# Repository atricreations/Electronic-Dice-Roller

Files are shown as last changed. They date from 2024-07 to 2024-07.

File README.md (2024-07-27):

# Electronic-Dice-Roller.

Repository containing all the necessary files for the Electronic Dice Roller by Atricreations. 

There are 3 primary components to this repository:
- Code: The main micro python files for the RP2040 micro controller.
- 3D-Models: STL files that make up the case.
- PCB: Ki-cad PCB design files.

### What do this do?
This is the current iteration of a long running project seeking to implement electronic dice. This design features:
- RP2040 Microcontroller
- Fully RGB 5x7 matrix display
- Lithium battery and charger

The code is fully open source and the design is to encourage tinkering. The current design isn't perfect but is highly functional. As updates are made they will be posted here. 

 If you like what is here consider buying one or some of the components off of our Etsy. 
### How do I modify the software on my dice? 
 All complete dice come sold with the current version of software installed. If you would like to update the software you need to copy the files from the Code directory onto your device. Primarily this is done through [Thonny](https://thonny.org/). 
 
When a source file is opened on Thonny and the correct interface is selected, you can upload the new source file onto the micorcontroller. All files need to be updated for them to work properly. 

### I need help!!!!
Don't hesitate to email us at Atricreations@gmail.com if you need help with your unit. We may take a while to respond but we can offer help if needed. 

### History:
-V 0.1: 7/26/2024 -  Initial Beta Release - Highly functional, lacks low power features, a few small bugs. 

## Todo: 
### PCB:
- Add Accelerometer.
- Add Speaker.
### 3D Models:
- Improved Tolerances.
### Code:
- Improved low power performance (possibly port to circuitpython).
- Various bug fixes.
- Some type of config file to determine color encoding.
- Some type of encoding for animations and other effects.
- PC application to upload configurations.
- Endless feature creep. 

## License
Electronic Dice Roller © 2024 by Atricareations is licensed under CC BY-NC 4.0. To view a copy of this license, visit https://creativecommons.org/licenses/by-nc/4.0/

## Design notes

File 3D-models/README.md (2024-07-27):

# 3D Models
This folder contains the mesh files for 3d printing. The top screen and buttons are multi part assemblies and really are intended to be printed multi-color to get the proper effect. 

A precolored bambulabs project is also included. 

Files were printed with a .2mm nozzle.

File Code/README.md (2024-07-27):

# Source code files
There are a handful of files that make up the source code of this device.

-char_set.py: Courtesy of chatgpt, this included the charaacter set used on the display. 
-config.py: Contains the configuration setting for the device. 
-main.py: Contains the main logic and functions. The entry point for the microcontroller. 
-neopixel.py: Contains the neopixel library.

For the most part, the only files that need to be modified are main.py and config.py, the other files are fairly static.

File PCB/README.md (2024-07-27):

# PCB Design files
This folder contains the Ki-Cad design files for the pCB including the PCB and layout. 

There really isnt much to say here, if you are fammiliar with PCB design you'll know what to do. If not, feel free to ask questions but the design isnt completely trivial.

The design uses all LCSC parts and can be ordered fully assembled through JLCPCB.

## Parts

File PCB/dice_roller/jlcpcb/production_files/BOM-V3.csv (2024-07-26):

Comment | Designator | Footprint | LCSC
1k | R17,R20,R6,R8 | R_0402_1005Metric | C11702
22uf | C10,C2,C5,C9 | C_0402_1005Metric | C15525
8p | C21,C22 | C_0402_1005Metric | C161335
1UH | L1 | IND-SMD_L4.4-W4.2 | C167203
0 | R10,R12,R14,R15,R16,R9 | R_0402_1005Metric | C17168
IP5306 | U1 | ESOP-8_L4.9-W3.9-P1.27-LS6.0-BL-EP | C181692
LED | D1 | LED_0603_1608Metric | C2286
20R | R21 | R_0402_1005Metric | C25092
10k | R4 | R_0402_1005Metric | C25744
5.1K | R1,R3 | R_0402_1005Metric | C25905
1M | R18,R19 | R_0402_1005Metric | C26083
TYPE-C 16PIN 2MD(073) | USB1 | USB-C-SMD_TYPE-C-6PIN-2MD-073 | C2765186
SK6805-EC20 | LED1,LED10,LED11,LED12,LED13,LED14,LED15,LED16,LED17,LED18,LED19,LED2,LED20,LED21,LED22,LED23,LED24,LED25,LED26,LED27,LED28,LED29,LED3,LED30,LED31,LED32,LED33,LED34,LED35,LED36,LED37,LED38,LED39,LED4,LED40,LED41,LED42,LED43,LED44,LED45,LED46,LED47,LED48,LED49,LED5,LED50,LED51,LED52,LED53,LED54,LED55,LED56,LED57,LED58,LED59,LED6,LED60,LED61,LED62,LED63,LED64,LED65,LED66,LED67,LED68,LED69,LED7,LED70,LED71,LED72,LED73,LED74,LED75,LED76,LED77,LED8,LED9 | LED-SMD_4P-L2.0-W2.0-BR | C2890036
100n | C1,C11,C12,C13,C14,C15,C16,C17,C18,C19,C23,C24,C25,C26,C27,C28,C29,C3,C30,C31,C32,C33,C34,C35,C36,C37,C38,C39,C4,C40,C41,C42,C43,C44,C45,C46,C47,C48,C49,C50,C51,C52,C53,C54,C55,C56,C57,C58,C59,C6,C60,C61,C62,C63,C64,C65,C66,C67,C7,C8 | C_0402_1005Metric | C307331
27.4 | R11,R13 | R_0402_1005Metric | C31439
BOOT | S2,S3,S4,S5,S6 | SW_TS-1187A-B-A-B | C318884
TS24CA | SW1 | SW-SMD_TS24CA | C393942
LM4040DBZ-2.0 | U2 | SOT-23 | C460725
0.5R | R2 | R_0402_1005Metric | C5204041
1u | C20 | C_0402_1005Metric | C52923
MCP1703Ax-330xxTT | U3 | SOT-23 | C5446
WTL2M45316LZ | X1 | CRYSTAL-SMD_4P-L2.5-W2.0-BL | C963522
W25Q128JVS | U4 | SOIC-8_5.23x5.23mm_P1.27mm | C97521
RP2040 | U5 | QFN-56-1EP_7x7mm_P0.4mm_EP3.2x3.2mm

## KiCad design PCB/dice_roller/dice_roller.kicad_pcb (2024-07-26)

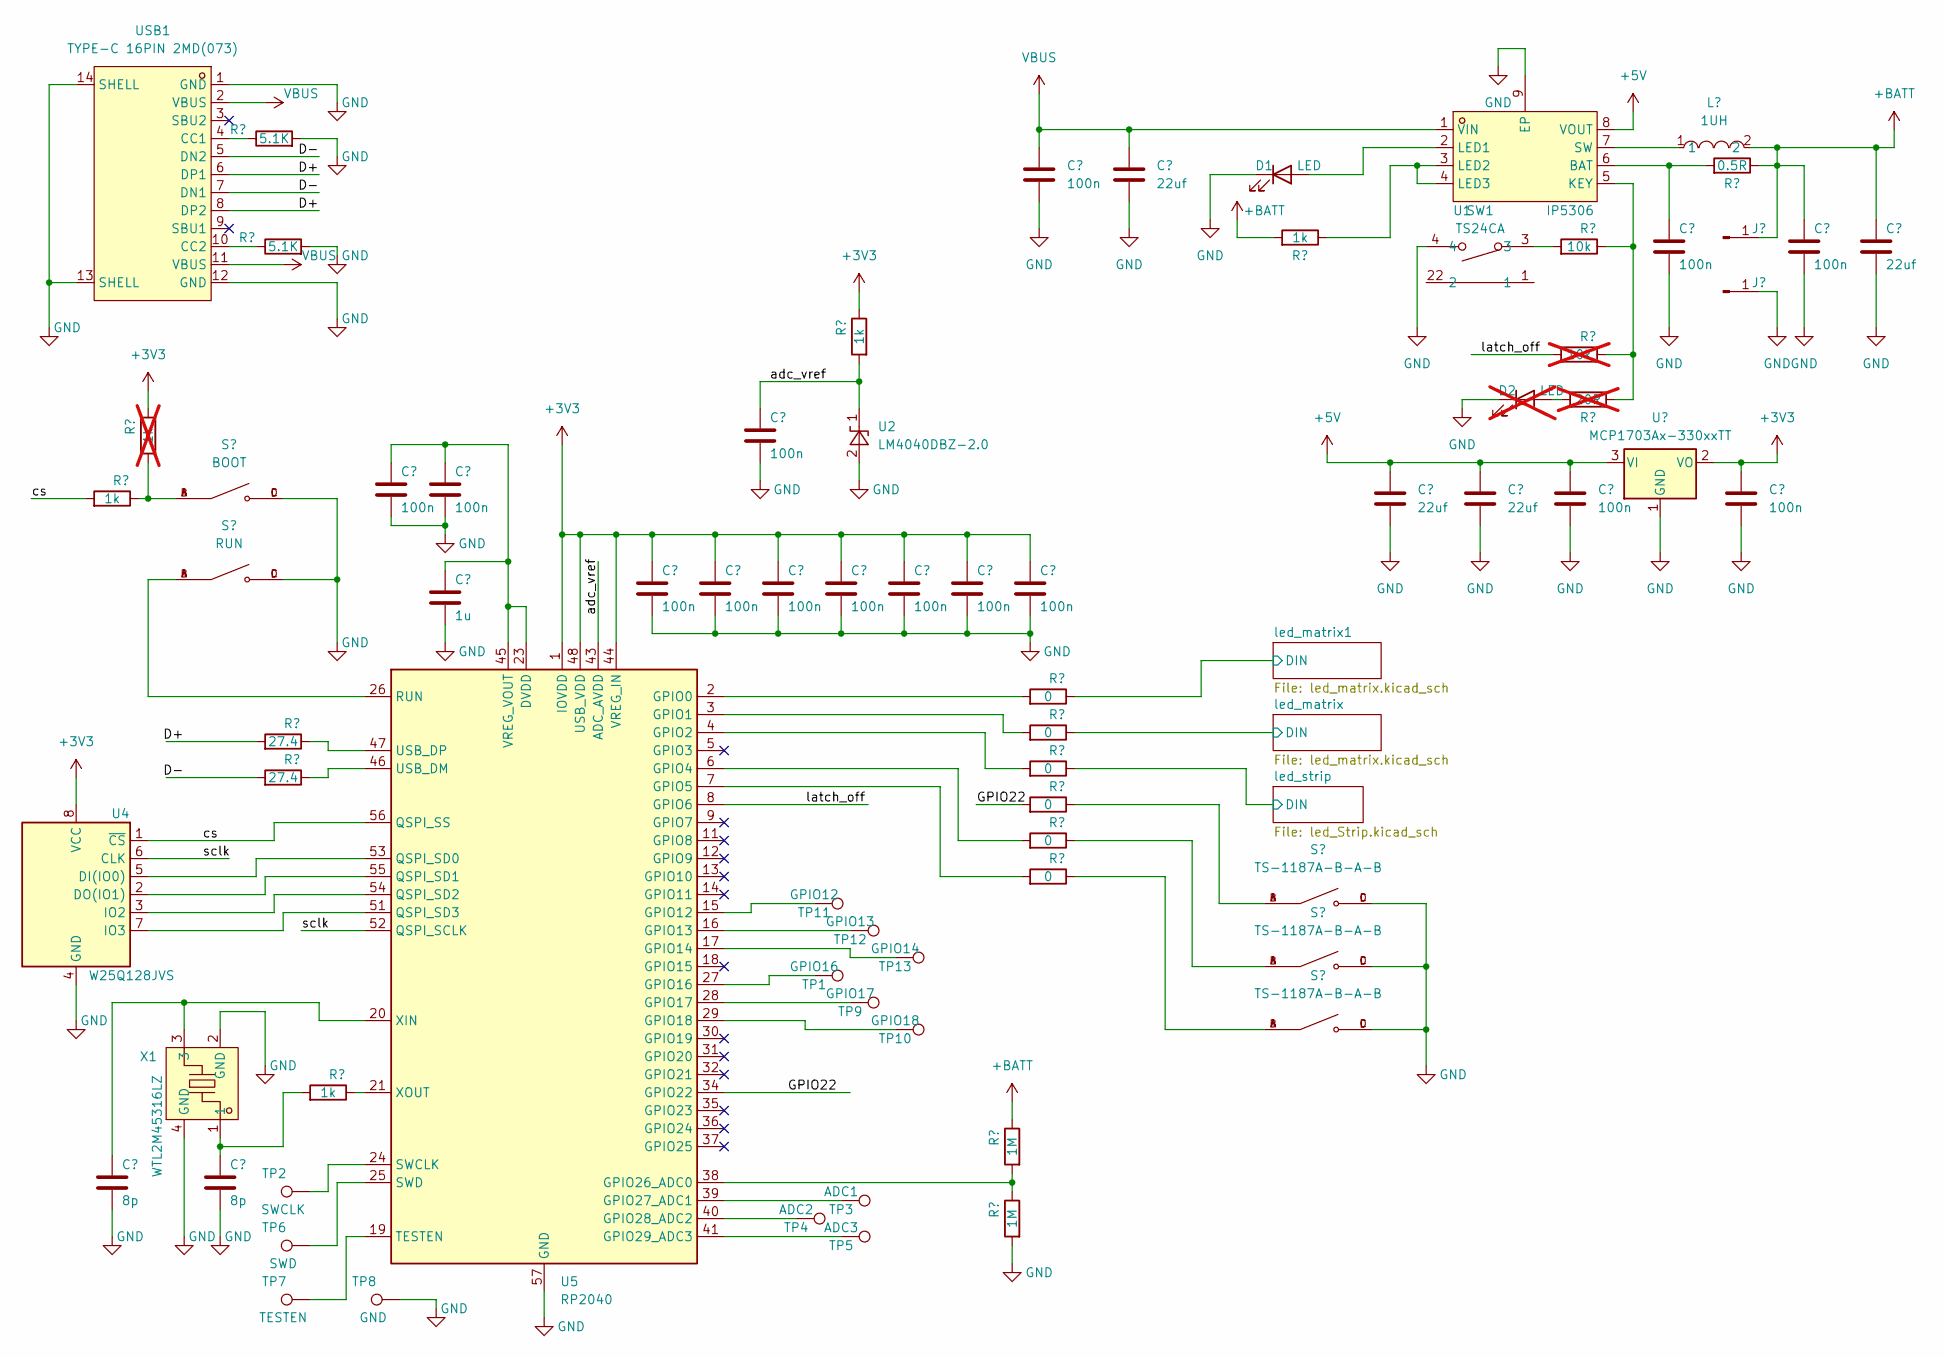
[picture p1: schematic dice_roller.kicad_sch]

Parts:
C1, C3, C4, C6, C7, C8, C11, C12, C13, C14, C15, C16, C17, C18, C19: 100n; C_0402_1005Metric
C2, C5, C9, C10: 22uf; C_0402_1005Metric
C20: 1u; C_0402_1005Metric
C21, C22: 8p; C_0402_1005Metric
D1: LED; LED_0603_1608Metric
D2: LED; LED_0603_1608Metric; not fitted
J1, J2: Conn_01x01_Pin; TestPoint_Pad_2.0x2.0mm
L1: 1UH; IND-SMD_L4.4-W4.2; LCSC Part C167203
R1, R3: 5.1K; R_0402_1005Metric
R2: 0.5R; R_0402_1005Metric
R4: 10k; R_0402_1005Metric
R5: 10k; R_0402_1005Metric; not fitted
R6, R8, R17, R20: 1k; R_0402_1005Metric
R7: 1k; R_0402_1005Metric; not fitted
R9, R10, R12, R14, R15, R16: 0; R_0402_1005Metric
R11, R13: 27.4; R_0402_1005Metric
R18, R19: 1M; R_0402_1005Metric
R21: 20R; R_0402_1005Metric; not fitted
S2: BOOT; SW_TS-1187A-B-A-B; PARTREV A0
S3: RUN; SW_TS-1187A-B-A-B; PARTREV A0
S4, S5, S6: TS-1187A-B-A-B; SW_TS-1187A-B-A-B; PARTREV A0
SW1: TS24CA; SW-SMD_TS24CA; LCSC Part C393942
TP1: GPIO16; TestPoint_Pad_D1.0mm
TP2: SWCLK; TestPoint_Pad_D1.0mm
TP3: ADC1; TestPoint_Pad_D1.0mm
TP4: ADC2; TestPoint_Pad_D1.0mm
TP5: ADC3; TestPoint_Pad_D1.0mm
TP6: SWD; TestPoint_Pad_D1.0mm
TP7: TESTEN; TestPoint_Pad_D1.0mm
TP8: GND; TestPoint_Pad_1.0x1.0mm
TP9: GPIO17; TestPoint_Pad_D1.0mm
TP10: GPIO18; TestPoint_Pad_D1.0mm
TP11: GPIO12; TestPoint_Pad_D1.0mm
TP12: GPIO13; TestPoint_Pad_D1.0mm
TP13: GPIO14; TestPoint_Pad_D1.0mm
U1: IP5306; ESOP-8_L4.9-W3.9-P1.27-LS6.0-BL-EP; LCSC Part C181692
U2: LM4040DBZ-2.0; SOT-23
U3: MCP1703Ax-330xxTT; SOT-23
U4: W25Q128JVS; SOIC-8_5.23x5.23mm_P1.27mm
U5: RP2040; QFN-56-1EP_7x7mm_P0.4mm_EP3.2x3.2mm
USB1: TYPE-C 16PIN 2MD(073); USB-C-SMD_TYPE-C-6PIN-2MD-073; LCSC Part C2765186
X1: WTL2M45316LZ; CRYSTAL-SMD_4P-L2.5-W2.0-BL; LCSC Part C963522

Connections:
+3V3: C12.1, C13.1, C14.1, C15.1, C16.1, C17.1, C18.1, C19.1, R6.1, R7.1, U3.2 (VO), U4.8 (VCC), U5.1 (IOVDD), U5.10 (IOVDD), U5.22 (IOVDD), U5.33 (IOVDD), U5.42 (IOVDD), U5.44 (VREG_IN), U5.48 (USB_VDD), U5.49 (IOVDD)
+5V: C9.1, C10.1, C11.1, U1.8 (VOUT), U3.3 (VI); also elsewhere on the board
+BATT: C4.1, C5.1, J1.1, L1.2, R2.1, R18.1, R20.2
/D+: R11.2, USB1.6 (DP1), USB1.8 (DP2)
/D-: R13.2, USB1.5 (DN2), USB1.7 (DN1)
/GPIO22: R14.2, U5.34 (GPIO22)
/adc_vref: C6.1, R6.2, U2.1 (K), U5.43 (ADC_AVDD)
/cs: R8.2, U4.1 (~CS), U5.56 (QSPI_SS)
/latch_off: R5.2, U5.8 (GPIO6)
/led_matrix1/DIN: R9.1; also elsewhere on the board
/led_matrix/DIN: R10.1; also elsewhere on the board
/led_strip/DIN: R12.1; also elsewhere on the board
/sclk: U4.6 (CLK), U5.52 (QSPI_SCLK)
GND: C1.2, C2.2, C3.2, C4.2, C5.2, C6.2, C7.2, C8.2, C9.2, C10.2, C11.2, C12.2, C13.2, C14.2, C15.2, C16.2, C17.2, C18.2, C19.2, C20.2, C21.2, C22.2, D1.1 (K), D2.1 (K), J2.1, R1.2, R3.2, R19.2, S2.C, S2.D, S3.C, S3.D, S4.C, S4.D, S5.C, S5.D, S6.C, S6.D, SW1.4, TP8.1, U1.9 (EP), U2.2 (A), U3.1 (GND), U4.4 (GND), U5.57 (GND), USB1.1 (GND), USB1.12 (GND), USB1.13 (SHELL), USB1.14 (SHELL), X1.2 (GND), X1.4 (GND); also elsewhere on the board
unnamed: C22.1, R17.2, X1.1
unnamed: D1.2 (A), U1.2 (LED1)
unnamed: D2.2 (A), R21.2
unnamed: R4.2, SW1.3
unnamed: R7.2, R8.1, S2.A, S2.B
unnamed: R14.1, S4.A, S4.B
unnamed: R15.1, S5.A, S5.B
unnamed: R16.1, S6.A, S6.B
unnamed: C3.1, R2.2, U1.6 (BAT)
unnamed: R4.1, R5.1, R21.1, U1.5 (KEY)
unnamed: R20.1, U1.3 (LED2), U1.4 (LED3)
unnamed: L1.1, U1.7 (SW)
unnamed: U4.5 (DI(IO0)), U5.53 (QSPI_SD0)
unnamed: U4.2 (DO(IO1)), U5.55 (QSPI_SD1)
unnamed: U4.3 (IO2), U5.54 (QSPI_SD2)
unnamed: U4.7 (IO3), U5.51 (QSPI_SD3)
unnamed: R9.2, U5.2 (GPIO0)
unnamed: R10.2, U5.3 (GPIO1)
unnamed: R12.2, U5.4 (GPIO2)
unnamed: R15.2, U5.6 (GPIO4)
unnamed: R16.2, U5.7 (GPIO5)
unnamed: TP11.1, U5.15 (GPIO12)
unnamed: TP12.1, U5.16 (GPIO13)
unnamed: TP13.1, U5.17 (GPIO14)
unnamed: TP1.1, U5.27 (GPIO16)
unnamed: TP9.1, U5.28 (GPIO17)
unnamed: TP10.1, U5.29 (GPIO18)
unnamed: R18.2, R19.1, U5.38 (GPIO26_ADC0)
unnamed: TP3.1, U5.39 (GPIO27_ADC1)
unnamed: TP4.1, U5.40 (GPIO28_ADC2)
unnamed: TP5.1, U5.41 (GPIO29_ADC3)
unnamed: S3.A, S3.B, U5.26 (RUN)
unnamed: TP2.1, U5.24 (SWCLK)
unnamed: TP6.1, U5.25 (SWD)
unnamed: TP7.1, U5.19 (TESTEN)
unnamed: R13.1, U5.46 (USB_DM)
unnamed: R11.1, U5.47 (USB_DP)
unnamed: C7.1, C8.1, C20.1, U5.23 (DVDD), U5.45 (VREG_VOUT), U5.50 (DVDD)
unnamed: C21.1, U5.20 (XIN), X1.3
unnamed: R17.1, U5.21 (XOUT)
unnamed: R1.1, USB1.4 (CC1)
unnamed: R3.1, USB1.10 (CC2)
VBUS: C1.1, C2.1, U1.1 (VIN), USB1.2 (VBUS), USB1.11 (VBUS)

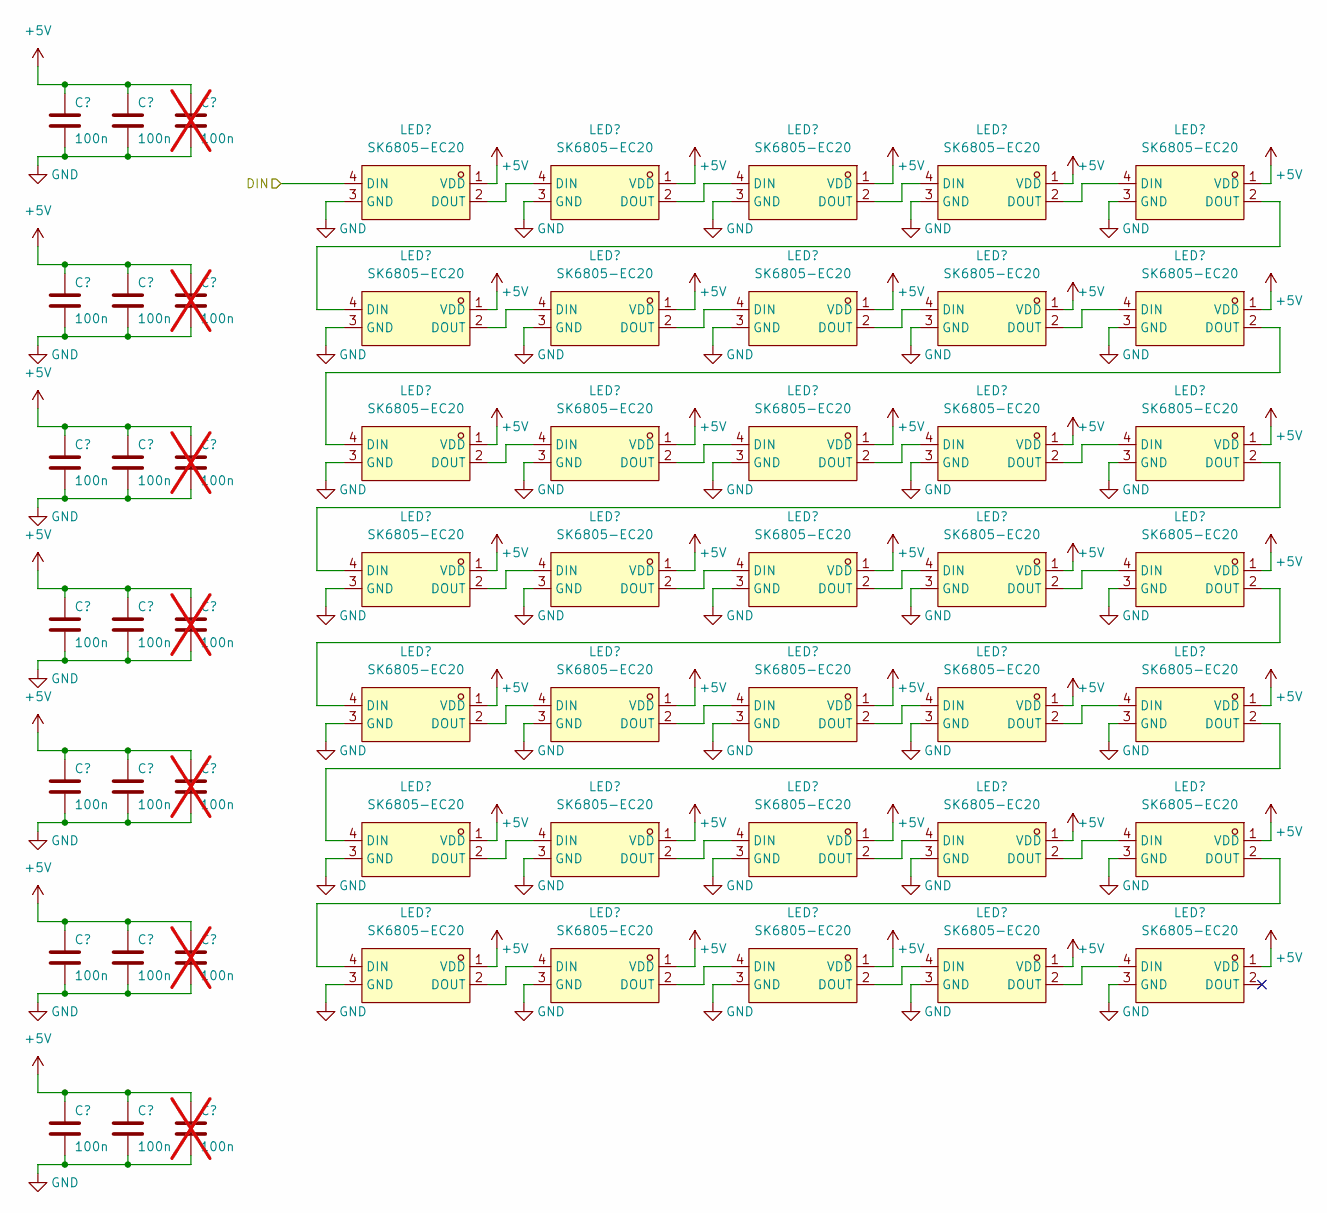
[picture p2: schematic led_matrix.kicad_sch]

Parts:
C23, C24, C26, C27, C29, C30, C32, C33, C35, C36, C38, C39, C41, C42: 100n; C_0402_1005Metric
C25, C28, C31, C34, C37, C40, C43: 100n; C_0402_1005Metric; not fitted
LED1, LED2, LED3, LED4, LED5, LED6, LED7, LED8, LED9, LED10, LED11, LED12, LED13, LED14, LED15, LED16, LED17, LED18, LED19, LED20, LED21, LED22, LED23, LED24, LED25, LED26, LED27, LED28, LED29, LED30, LED31, LED32, LED33, LED34, LED35: SK6805-EC20; LED-SMD_4P-L2.0-W2.0-BR; LCSC Part C2890036

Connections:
+5V: C23.1, C24.1, C25.1, C26.1, C27.1, C28.1, C29.1, C30.1, C31.1, C32.1, C33.1, C34.1, C35.1, C36.1, C37.1, C38.1, C39.1, C40.1, C41.1, C42.1, C43.1, LED1.1 (VDD), LED2.1 (VDD), LED3.1 (VDD), LED4.1 (VDD), LED5.1 (VDD), LED6.1 (VDD), LED7.1 (VDD), LED8.1 (VDD), LED9.1 (VDD), LED10.1 (VDD), LED11.1 (VDD), LED12.1 (VDD), LED13.1 (VDD), LED14.1 (VDD), LED15.1 (VDD), LED16.1 (VDD), LED17.1 (VDD), LED18.1 (VDD), LED19.1 (VDD), LED20.1 (VDD), LED21.1 (VDD), LED22.1 (VDD), LED23.1 (VDD), LED24.1 (VDD), LED25.1 (VDD), LED26.1 (VDD), LED27.1 (VDD), LED28.1 (VDD), LED29.1 (VDD), LED30.1 (VDD), LED31.1 (VDD), LED32.1 (VDD), LED33.1 (VDD), LED34.1 (VDD), LED35.1 (VDD); also elsewhere on the board
/led_matrix/DIN: LED1.4 (DIN); also elsewhere on the board
GND: C23.2, C24.2, C25.2, C26.2, C27.2, C28.2, C29.2, C30.2, C31.2, C32.2, C33.2, C34.2, C35.2, C36.2, C37.2, C38.2, C39.2, C40.2, C41.2, C42.2, C43.2, LED1.3 (GND), LED2.3 (GND), LED3.3 (GND), LED4.3 (GND), LED5.3 (GND), LED6.3 (GND), LED7.3 (GND), LED8.3 (GND), LED9.3 (GND), LED10.3 (GND), LED11.3 (GND), LED12.3 (GND), LED13.3 (GND), LED14.3 (GND), LED15.3 (GND), LED16.3 (GND), LED17.3 (GND), LED18.3 (GND), LED19.3 (GND), LED20.3 (GND), LED21.3 (GND), LED22.3 (GND), LED23.3 (GND), LED24.3 (GND), LED25.3 (GND), LED26.3 (GND), LED27.3 (GND), LED28.3 (GND), LED29.3 (GND), LED30.3 (GND), LED31.3 (GND), LED32.3 (GND), LED33.3 (GND), LED34.3 (GND), LED35.3 (GND); also elsewhere on the board
unnamed: LED1.2 (DOUT), LED2.4 (DIN)
unnamed: LED2.2 (DOUT), LED3.4 (DIN)
unnamed: LED3.2 (DOUT), LED4.4 (DIN)
unnamed: LED4.2 (DOUT), LED5.4 (DIN)
unnamed: LED5.2 (DOUT), LED6.4 (DIN)
unnamed: LED6.2 (DOUT), LED7.4 (DIN)
unnamed: LED7.2 (DOUT), LED8.4 (DIN)
unnamed: LED8.2 (DOUT), LED9.4 (DIN)
unnamed: LED9.2 (DOUT), LED10.4 (DIN)
unnamed: LED10.2 (DOUT), LED11.4 (DIN)
unnamed: LED11.2 (DOUT), LED12.4 (DIN)
unnamed: LED12.2 (DOUT), LED13.4 (DIN)
unnamed: LED13.2 (DOUT), LED14.4 (DIN)
unnamed: LED14.2 (DOUT), LED15.4 (DIN)
unnamed: LED15.2 (DOUT), LED16.4 (DIN)
unnamed: LED16.2 (DOUT), LED17.4 (DIN)
unnamed: LED17.2 (DOUT), LED18.4 (DIN)
unnamed: LED18.2 (DOUT), LED19.4 (DIN)
unnamed: LED19.2 (DOUT), LED20.4 (DIN)
unnamed: LED20.2 (DOUT), LED21.4 (DIN)
unnamed: LED21.2 (DOUT), LED22.4 (DIN)
unnamed: LED22.2 (DOUT), LED23.4 (DIN)
unnamed: LED23.2 (DOUT), LED24.4 (DIN)
unnamed: LED24.2 (DOUT), LED25.4 (DIN)
unnamed: LED25.2 (DOUT), LED26.4 (DIN)
unnamed: LED26.2 (DOUT), LED27.4 (DIN)
unnamed: LED27.2 (DOUT), LED28.4 (DIN)
unnamed: LED28.2 (DOUT), LED29.4 (DIN)
unnamed: LED29.2 (DOUT), LED30.4 (DIN)
unnamed: LED30.2 (DOUT), LED31.4 (DIN)
unnamed: LED31.2 (DOUT), LED32.4 (DIN)
unnamed: LED32.2 (DOUT), LED33.4 (DIN)
unnamed: LED33.2 (DOUT), LED34.4 (DIN)
unnamed: LED34.2 (DOUT), LED35.4 (DIN)

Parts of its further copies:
C44, C45, C47, C48, C50, C51, C53, C54, C56, C57, C59, C60, C62, C63: 100n; C_0402_1005Metric
C46, C49, C52, C55, C58, C61, C64: 100n; C_0402_1005Metric; not fitted
LED36, LED37, LED38, LED39, LED40, LED41, LED42, LED43, LED44, LED45, LED46, LED47, LED48, LED49, LED50, LED51, LED52, LED53, LED54, LED55, LED56, LED57, LED58, LED59, LED60, LED61, LED62, LED63, LED64, LED65, LED66, LED67, LED68, LED69, LED70: SK6805-EC20; LED-SMD_4P-L2.0-W2.0-BR; LCSC Part C2890036

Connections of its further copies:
+5V: C44.1, C45.1, C46.1, C47.1, C48.1, C49.1, C50.1, C51.1, C52.1, C53.1, C54.1, C55.1, C56.1, C57.1, C58.1, C59.1, C60.1, C61.1, C62.1, C63.1, C64.1, LED36.1 (VDD), LED37.1 (VDD), LED38.1 (VDD), LED39.1 (VDD), LED40.1 (VDD), LED41.1 (VDD), LED42.1 (VDD), LED43.1 (VDD), LED44.1 (VDD), LED45.1 (VDD), LED46.1 (VDD), LED47.1 (VDD), LED48.1 (VDD), LED49.1 (VDD), LED50.1 (VDD), LED51.1 (VDD), LED52.1 (VDD), LED53.1 (VDD), LED54.1 (VDD), LED55.1 (VDD), LED56.1 (VDD), LED57.1 (VDD), LED58.1 (VDD), LED59.1 (VDD), LED60.1 (VDD), LED61.1 (VDD), LED62.1 (VDD), LED63.1 (VDD), LED64.1 (VDD), LED65.1 (VDD), LED66.1 (VDD), LED67.1 (VDD), LED68.1 (VDD), LED69.1 (VDD), LED70.1 (VDD); also elsewhere on the board
/led_matrix1/DIN: LED36.4 (DIN); also elsewhere on the board
GND: C44.2, C45.2, C46.2, C47.2, C48.2, C49.2, C50.2, C51.2, C52.2, C53.2, C54.2, C55.2, C56.2, C57.2, C58.2, C59.2, C60.2, C61.2, C62.2, C63.2, C64.2, LED36.3 (GND), LED37.3 (GND), LED38.3 (GND), LED39.3 (GND), LED40.3 (GND), LED41.3 (GND), LED42.3 (GND), LED43.3 (GND), LED44.3 (GND), LED45.3 (GND), LED46.3 (GND), LED47.3 (GND), LED48.3 (GND), LED49.3 (GND), LED50.3 (GND), LED51.3 (GND), LED52.3 (GND), LED53.3 (GND), LED54.3 (GND), LED55.3 (GND), LED56.3 (GND), LED57.3 (GND), LED58.3 (GND), LED59.3 (GND), LED60.3 (GND), LED61.3 (GND), LED62.3 (GND), LED63.3 (GND), LED64.3 (GND), LED65.3 (GND), LED66.3 (GND), LED67.3 (GND), LED68.3 (GND), LED69.3 (GND), LED70.3 (GND); also elsewhere on the board
unnamed: LED36.2 (DOUT), LED37.4 (DIN)
unnamed: LED37.2 (DOUT), LED38.4 (DIN)
unnamed: LED38.2 (DOUT), LED39.4 (DIN)
unnamed: LED39.2 (DOUT), LED40.4 (DIN)
unnamed: LED40.2 (DOUT), LED41.4 (DIN)
unnamed: LED41.2 (DOUT), LED42.4 (DIN)
unnamed: LED42.2 (DOUT), LED43.4 (DIN)
unnamed: LED43.2 (DOUT), LED44.4 (DIN)
unnamed: LED44.2 (DOUT), LED45.4 (DIN)
unnamed: LED45.2 (DOUT), LED46.4 (DIN)
unnamed: LED46.2 (DOUT), LED47.4 (DIN)
unnamed: LED47.2 (DOUT), LED48.4 (DIN)
unnamed: LED48.2 (DOUT), LED49.4 (DIN)
unnamed: LED49.2 (DOUT), LED50.4 (DIN)
unnamed: LED50.2 (DOUT), LED51.4 (DIN)
unnamed: LED51.2 (DOUT), LED52.4 (DIN)
unnamed: LED52.2 (DOUT), LED53.4 (DIN)
unnamed: LED53.2 (DOUT), LED54.4 (DIN)
unnamed: LED54.2 (DOUT), LED55.4 (DIN)
unnamed: LED55.2 (DOUT), LED56.4 (DIN)
unnamed: LED56.2 (DOUT), LED57.4 (DIN)
unnamed: LED57.2 (DOUT), LED58.4 (DIN)
unnamed: LED58.2 (DOUT), LED59.4 (DIN)
unnamed: LED59.2 (DOUT), LED60.4 (DIN)
unnamed: LED60.2 (DOUT), LED61.4 (DIN)
unnamed: LED61.2 (DOUT), LED62.4 (DIN)
unnamed: LED62.2 (DOUT), LED63.4 (DIN)
unnamed: LED63.2 (DOUT), LED64.4 (DIN)
unnamed: LED64.2 (DOUT), LED65.4 (DIN)
unnamed: LED65.2 (DOUT), LED66.4 (DIN)
unnamed: LED66.2 (DOUT), LED67.4 (DIN)
unnamed: LED67.2 (DOUT), LED68.4 (DIN)
unnamed: LED68.2 (DOUT), LED69.4 (DIN)
unnamed: LED69.2 (DOUT), LED70.4 (DIN)

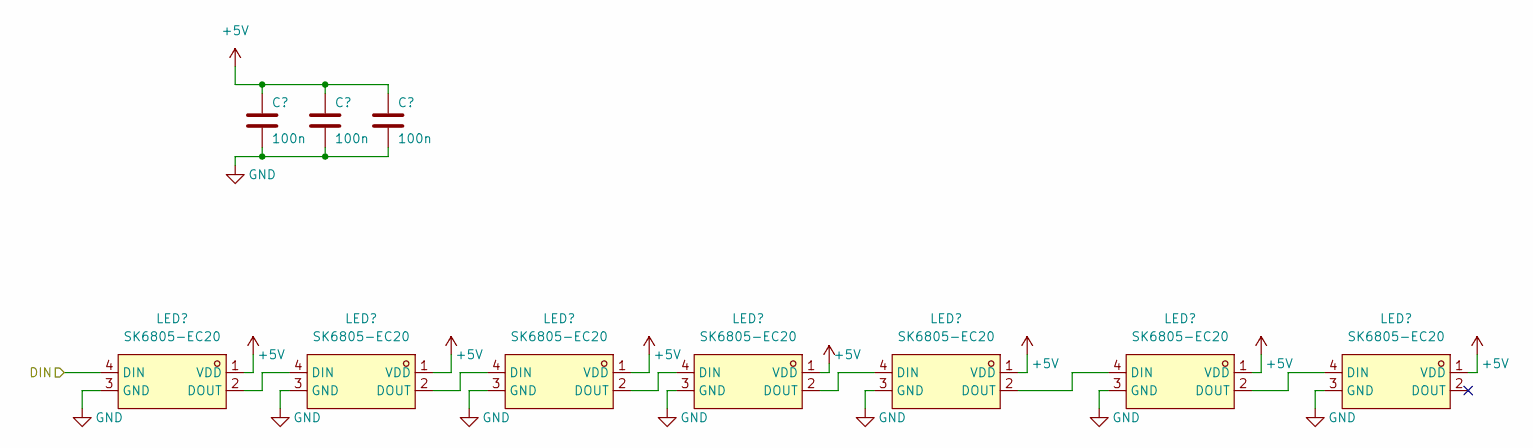
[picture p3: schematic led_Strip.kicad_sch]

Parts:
C65, C66, C67: 100n; C_0402_1005Metric
LED71, LED72, LED73, LED74, LED75, LED76, LED77: SK6805-EC20; LED-SMD_4P-L2.0-W2.0-BR; LCSC Part C2890036

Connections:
+5V: C65.1, C66.1, C67.1, LED71.1 (VDD), LED72.1 (VDD), LED73.1 (VDD), LED74.1 (VDD), LED75.1 (VDD), LED76.1 (VDD), LED77.1 (VDD); also elsewhere on the board
/led_strip/DIN: LED71.4 (DIN); also elsewhere on the board
GND: C65.2, C66.2, C67.2, LED71.3 (GND), LED72.3 (GND), LED73.3 (GND), LED74.3 (GND), LED75.3 (GND), LED76.3 (GND), LED77.3 (GND); also elsewhere on the board
unnamed: LED71.2 (DOUT), LED72.4 (DIN)
unnamed: LED72.2 (DOUT), LED73.4 (DIN)
unnamed: LED73.2 (DOUT), LED74.4 (DIN)
unnamed: LED74.2 (DOUT), LED75.4 (DIN)
unnamed: LED75.2 (DOUT), LED76.4 (DIN)
unnamed: LED76.2 (DOUT), LED77.4 (DIN)

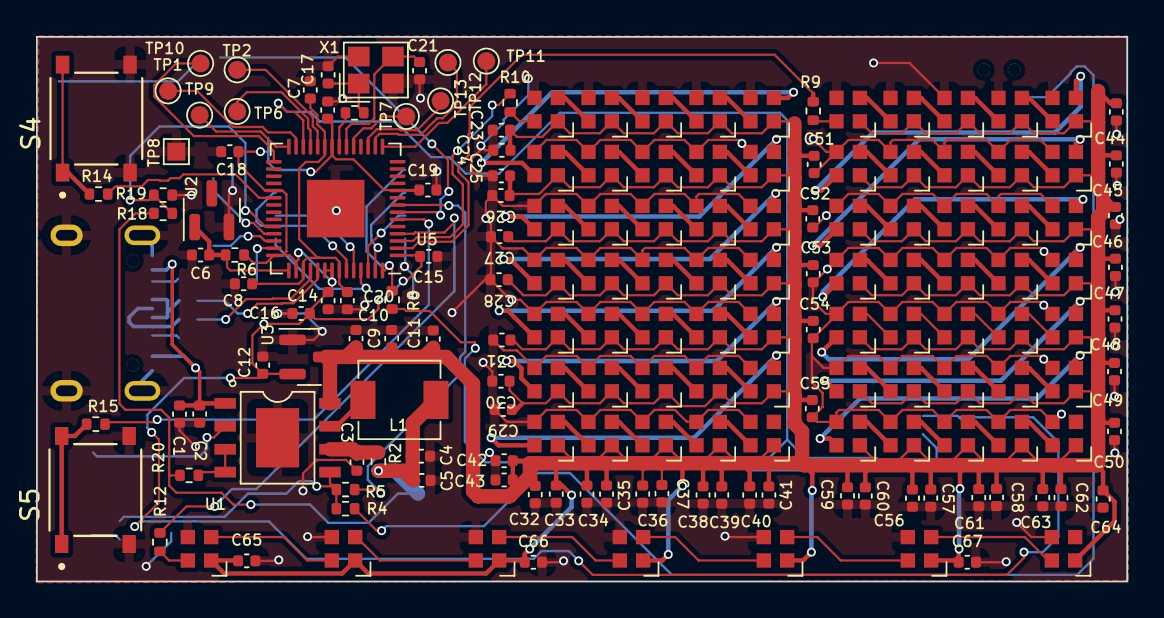
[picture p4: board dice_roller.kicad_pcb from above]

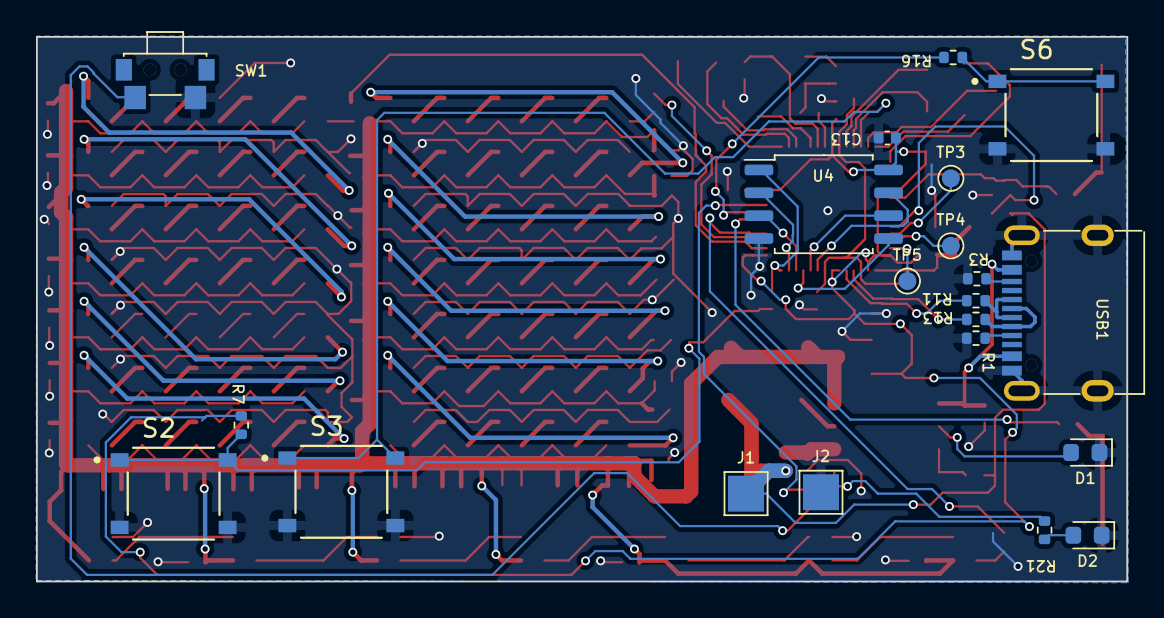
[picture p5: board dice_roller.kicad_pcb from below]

Board: 2 copper layers, 60.6 x 30.3 mm, 196 parts (21 on the bottom side), 131 nets.

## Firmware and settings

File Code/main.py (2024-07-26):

from neopixel import Neopixel
from char_set import char_set
import time
from machine import Pin,ADC,Timer
import random
from config import ones_color, tens_color,sel_color

random.seed()

battery_voltage = ADC(Pin(26))

roll_btn = Pin(4, Pin.IN, machine.Pin.PULL_UP)

switch_btn = Pin(22, Pin.IN, machine.Pin.PULL_UP)

vref = 2.5

n_pixels = 35

pixels = Neopixel(35, 0, 0, "GRB")
pixels_2 = Neopixel(35, 1, 1, "GRB")
pixels_3 = Neopixel(7, 2, 2, "GRB")

# start the timer
start = time.ticks_ms()
debounce_timer = time.ticks_ms()
display_timer = time.ticks_ms()
event_triggered = False

#Display interrupt 60hz/16ms:
def interruption_handler(timer):
    pixels.show()
    pixels_2.show()
    pixels_3.show()
    
show_display = Timer(mode=Timer.PERIODIC, period=16, callback=interruption_handler)
    

#display_vars:
ones = "0"
tens = "0"
value = 0
sel = 0
sleeping = False
display_update = True

button_pressed = None
d_list = [4,6,8,10,12,20,100]

#state_vars:
mode = "roller"
def animation_speckle(n_frames,max_brightness):
    
    for x in range(n_frames):
        for i in range(n_pixels):
            brightness = max_brightness * random.random() 
            pixels.set_pixel(i,[random.random() * brightness,random.random() * brightness,random.random() * brightness])
            pixels_2.set_pixel(i,[random.random() * brightness,random.random() * brightness,random.random() * brightness])
            #pixels.show()
            #pixels_2.show()
def mode_roller(button_pressed):
    global sel
    global ones
    global tens

    if button_pressed==22:
        sel = sel+1
        if sel > 6:
            sel=0
    if button_pressed==4:
        animation_speckle(25,15)
        value =  random.randrange(1, d_list[sel]+1)
        if value == 100:
            value=0
        ones=chr(value%10 +48)
        tens=chr(int(value/10)+48)
def mode_life_counter(button_pressed):
    global value
    global ones
    global tens
    if button_pressed==22:
        value=value+1
    if button_pressed==4:
        value=value-1
    print(value)
    ones=chr(value%10 +48)
    tens=chr(int(value/10)+48)
def process_button(button_pressed):
    global start
    global d_list
    global mode
    
    print("hi")
    print(button_pressed)

    #look for double click
    delta = time.ticks_diff(time.ticks_ms(), start)
    start = time.ticks_ms() # get millisecond counter
    if delta < 300:
        double_click=True
        
    if mode == "roller":
        mode_roller(button_pressed)
    if mode == "life_counter":
        mode_life_counter(button_pressed)
    # Update display:
    draw_char(ones, pixels,ones_color)
    draw_char(tens, pixels_2,tens_color)
        
    pixels_3.clear()
    pixels_3.set_pixel(sel,sel_color)
    print("hi")
    
    
def button_callback(p):
    global debounce_timer
    global button_pressed

    #Disable interrupts and start debounce timer.
    button_pressed = None
    debounce_timer = time.ticks_ms()

    roll_btn.irq(handler=None)
    switch_btn.irq(handler=None)


def draw_char(char, display,color):
    for i,line in enumerate(char_set[char]):
        for pixel in range(5):
            if (line >> (4 - pixel%5) & 0x1) == 0x1:
                display.set_pixel(pixel + i*5,color)
            else:
                display.set_pixel(pixel+ i*5,[0,0,0])
    #display.show()



while(1):
    sample_button = time.ticks_diff(time.ticks_ms(), debounce_timer)
    if sample_button > 2000:
        if switch_btn.value() == 0:
            debounce_timer = time.ticks_ms()
            if mode == "roller":
                value = 39
                mode = "life_counter"
            else:
                mode = "roller"
            process_button(22)
    #Sample the button after debounce expires.       
    if sample_button > 30:     
        if switch_btn.value() == 0:
            button_pressed = 22
        elif roll_btn.value() == 0:
            button_pressed = 4
        #on rising edge, reenable interrupts
        elif switch_btn.value() == 1 or roll_btn.value() == 1:
            roll_btn.irq(trigger=Pin.IRQ_FALLING, handler=button_callback)
            switch_btn.irq(trigger=Pin.IRQ_FALLING, handler=button_callback)
            button_pressed = None
            event_triggered = False
            
        if button_pressed != None and not event_triggered:
            process_button(button_pressed)
            event_triggered = True
            sleeping = False
            
            
    if sample_button > 8000 and button_pressed == None and sleeping == False:
        print("sleepy time")
        pixels.clear()
        pixels_2.clear()
        pixels_3.clear()
        sleeping = True
        

def display_test():
    for x in range(100):
        pot_value = battery_voltage.read_u16() # read value, 0-65535 across voltage range 0.0v - 3.3v
        voltage = vref/65535 * pot_value * 2
        print(pot_value)
        print(voltage)
        ones=chr(x%10 +48)
        tens=chr(int(x/10)+48)
        draw_char(ones, pixels,[2,7,4])
        draw_char(tens, pixels_2,[5,5,0])
        time.sleep(.1)            

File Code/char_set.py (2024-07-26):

#Courtesy of chat GPT. 
char_set = {
    # Uppercase letters
    "A": [
        0b01110,
        0b10001,
        0b10001,
        0b11111,
        0b10001,
        0b10001,
        0b10001
    ],
    "B": [
        0b11110,
        0b10001,
        0b10001,
        0b11110,
        0b10001,
        0b10001,
        0b11110
    ],
    "C": [
        0b01110,
        0b10001,
        0b10000,
        0b10000,
        0b10000,
        0b10001,
        0b01110
    ],
    "D": [
        0b11110,
        0b10001,
        0b10001,
        0b10001,
        0b10001,
        0b10001,
        0b11110
    ],
    "E": [
        0b11111,
        0b10000,
        0b10000,
        0b11110,
        0b10000,
        0b10000,
        0b11111
    ],
    "F": [
        0b11111,
        0b10000,
        0b10000,
        0b11110,
        0b10000,
        0b10000,
        0b10000
    ],
    "G": [
        0b01110,
        0b10001,
        0b10000,
        0b10111,
        0b10001,
        0b10001,
        0b01110
    ],
    "H": [
        0b10001,
        0b10001,
        0b10001,
        0b11111,
        0b10001,
        0b10001,
        0b10001
    ],
    "I": [
        0b01110,
        0b00100,
        0b00100,
        0b00100,
        0b00100,
        0b00100,
        0b01110
    ],
    "J": [
        0b11111,
        0b00010,
        0b00010,
        0b00010,
        0b00010,
        0b10010,
        0b01100
    ],
    "K": [
        0b10001,
        0b10010,
        0b10100,
        0b11000,
        0b10100,
        0b10010,
        0b10001
    ],
    "L": [
        0b10000,
        0b10000,
        0b10000,
        0b10000,
        0b10000,
        0b10000,
        0b11111
    ],
    "M": [
        0b10001,
        0b11011,
        0b10101,
        0b10101,
        0b10001,
        0b10001,
        0b10001
    ],
    "N": [
        0b10001,
        0b11001,
        0b10101,
        0b10011,
        0b10001,
        0b10001,
        0b10001
    ],
    "O": [
        0b01110,
        0b10001,
        0b10001,
        0b10001,
        0b10001,
        0b10001,
        0b01110
    ],
    "P": [
        0b11110,
        0b10001,
        0b10001,
        0b11110,
        0b10000,
        0b10000,
        0b10000
    ],
    "Q": [
        0b01110,
        0b10001,
        0b10001,
        0b10001,
        0b10101,
        0b10010,
        0b01101
    ],
    "R": [
        0b11110,
        0b10001,
        0b10001,
        0b11110,
        0b10100,
        0b10010,
        0b10001
    ],
    "S": [
        0b01111,
        0b10000,
        0b10000,
        0b01110,
        0b00001,
        0b00001,
        0b11110
    ],
    "T": [
        0b11111,
        0b00100,
        0b00100,
        0b00100,
        0b00100,
        0b00100,
        0b00100
    ],
    "U": [
        0b10001,
        0b10001,
        0b10001,
        0b10001,
        0b10001,
        0b10001,
        0b01110
    ],
    "V": [
        0b10001,
        0b10001,
        0b10001,
        0b10001,
        0b10001,
        0b01010,
        0b00100
    ],
    "W": [
        0b10001,
        0b10001,
        0b10001,
        0b10101,
        0b10101,
        0b10101,
        0b01010
    ],
    "X": [
        0b10001,
        0b10001,
        0b01010,
        0b00100,
        0b01010,
        0b10001,
        0b10001
    ],
    "Y": [
        0b10001,
        0b10001,
        0b10001,
        0b01010,
        0b00100,
        0b00100,
        0b00100
    ],
    "Z": [
        0b11111,
        0b00001,
        0b00010,
        0b00100,
        0b01000,
        0b10000,
        0b11111
    ],

    # Numbers
    "0": [
        0b01110,
        0b10001,
        0b10011,
        0b10101,
        0b11001,
        0b10001,
        0b01110
    ],
    "1": [
        0b00100,
        0b01100,
        0b00100,
        0b00100,
        0b00100,
        0b00100,
        0b11111
    ],
    "2": [
        0b01110,
        0b10001,
        0b00001,
        0b00010,
        0b00100,
        0b01000,
        0b11111
    ],
    "3": [
        0b11111,
        0b00010,
        0b00100,
        0b00010,
        0b00001,
        0b10001,
        0b01110
    ],
    "4": [
        0b00010,
        0b00110,
        0b01010,
        0b10010,
        0b11111,
        0b00010,
        0b00010
    ],
    "5": [
        0b11111,
        0b10000,
        0b11110,
        0b00001,
        0b00001,
        0b10001,
        0b01110
    ],
    "6": [
        0b00110,
        0b01000,
        0b10000,
        0b11110,
        0b10001,
        0b10001,
        0b01110
    ],
    "7": [
        0b11111,
        0b00001,
        0b00010,
        0b00100,
        0b01000,
        0b10000,
        0b10000
    ],
    "8": [
        0b01110,
        0b10001,
        0b10001,
        0b01110,
        0b10001,
        0b10001,
        0b01110
    ],
    "9": [
        0b01110,
        0b10001,
        0b10001,
        0b01111,
        0b00001,
        0b00010,
        0b01100
    ],
}
